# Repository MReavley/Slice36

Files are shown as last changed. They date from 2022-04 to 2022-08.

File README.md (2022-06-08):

# Slice36 Minimalist Split Keyboard

Picture of the Slice36

36 key ergo split keyboard, designed around the Seeeduino Xiao platform. Inspired by the Corne, Ferris, Ben Vallack's videos and countless hours of perusing reddit and kbd.news, but ultimately this has been done up from scratch largely as an exercise for myself. The layout was generated through experimentation with scale drawings on my ipad, although emphasis has been placed on aesthetics and compactness. 

## Features

-MX Spacing  
-Reversible PCB, designed around 0805 smd components to be hand-solderable or using an assembly service.  
-Built around the Seeeduino Xiao RP2040(hooray USB-C), using KMK.  
-Laser cut aluminium plate, secured by the soldered in switches for clean look without fasteners  

Picture of the Slice36 and PCB

## BOM
-Seeeduino Xiao RP2040 x2  
-1N4148WS Diodes (SOD-323) x36  
-PJ320D TRRS jacks x2  
-0805 10k resistors x6   
-(additional footprints R4-R7 for I2C communication for splits, may not be required)  
-Cherry MX style switches x36  
-Plate x2   
-TRRS cable  

## Things to note if you want to build one:

-IMPORTANT: The xiao on the right half (master) is to be soldered with the LED/chip facing up, and the left half (slave) upside down, so that the pinout still matches the flipped PCB.  

-You can find the schematic, layout and gerbers in the repo, as well as a dxf file for the plate. I am currently working on a case for this and will add the stls and solidworks files once they are ready. 

-I use 8mm rubber feet that are 1.5mm tall which are just about tall enough, but I think taller rubber feet would be better.

-TRRS jacks for the split are connected to the I2C pins on the Xiao board. Since KMK uses UART for split communications, I used PIO on the RP2040 to change those pins to UART, but I don't know what your options are on the SAMD21 version if you wish to use UART on those.  

-From my first prototype, I found that the SAMD21 version of the Xiao required external pullups on the I2C lines, so I added those to this board, and I have not tested if they are necessary yet. Currently I am using 10k resistors (to simplify my BOM), and it is working fine.  

-The Xiao BLE version should also be compatible with this board, but I have not made any provisions for batteries on this version. In theory only minimal modifications would be necessary to get this going though.  

Picture of the Slice36 and PCB
Picture of the Slice36 and PCB

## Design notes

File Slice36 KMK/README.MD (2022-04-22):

Added the files I use with my current board (including my keymap with some custom macros). 
Also added the mpy file needed to use pio with the board for convenience.

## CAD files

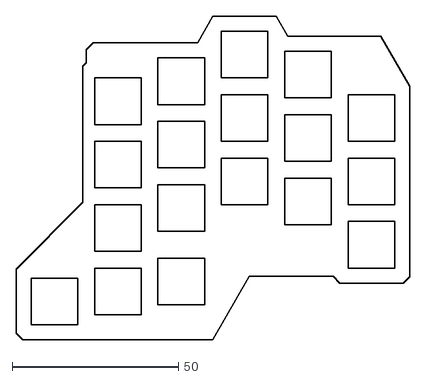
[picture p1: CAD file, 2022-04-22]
Plate/Slice36 Plate.dxf
118.3 x 97.2

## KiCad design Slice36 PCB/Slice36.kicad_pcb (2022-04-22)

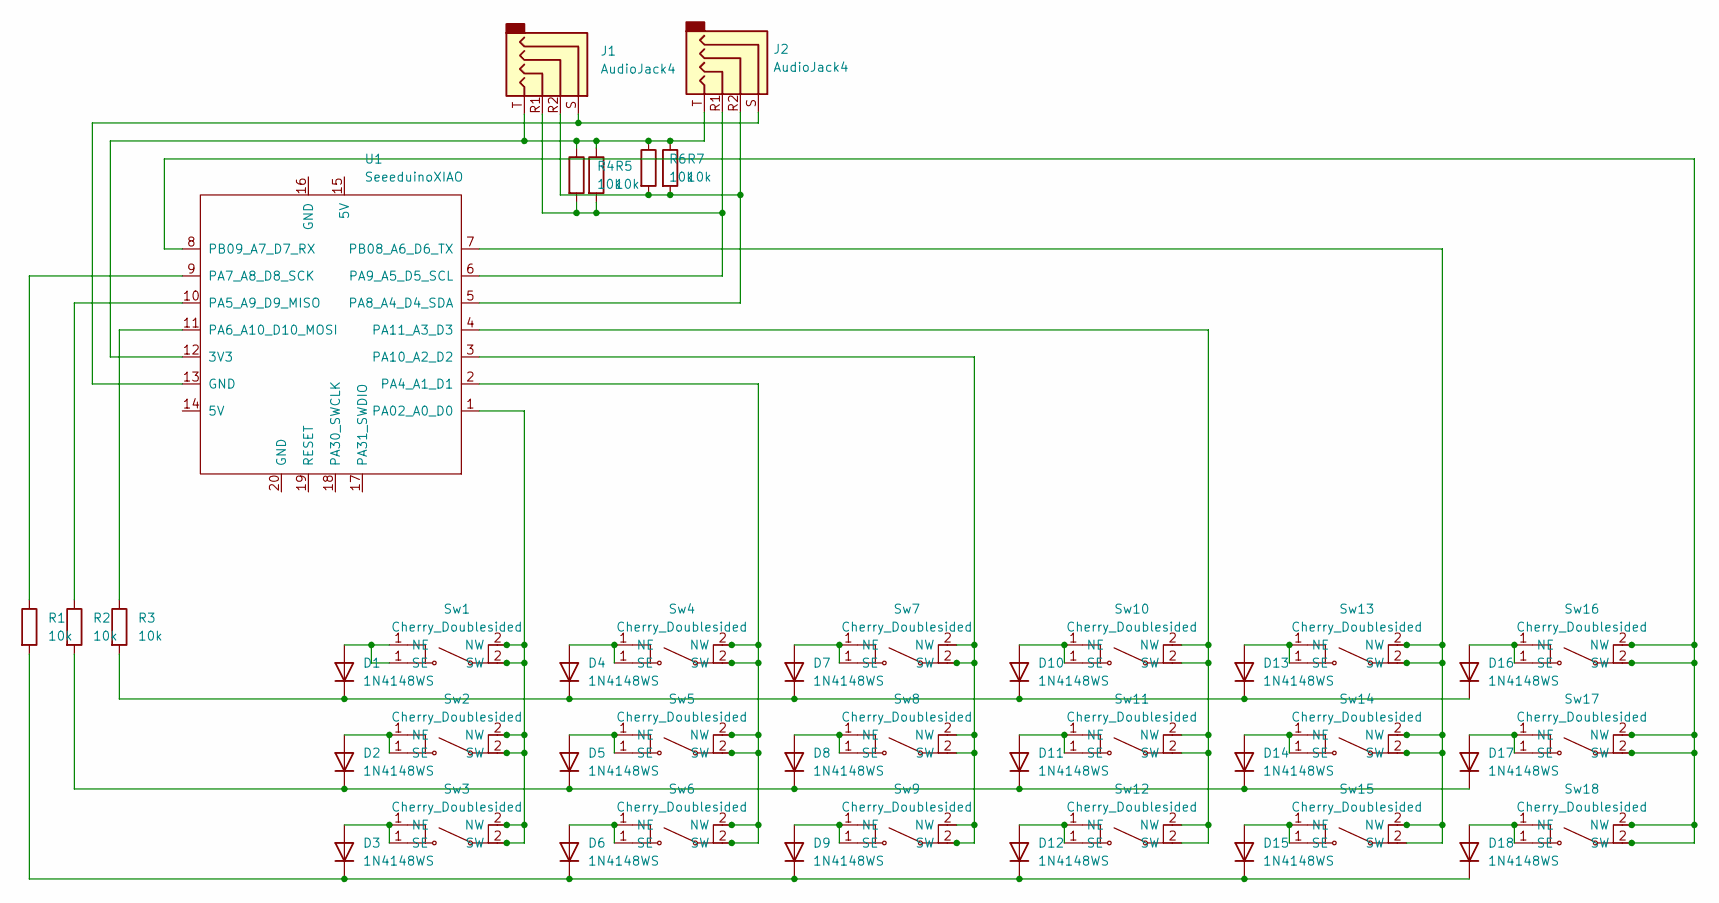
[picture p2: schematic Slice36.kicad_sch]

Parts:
D1, D2, D3, D4, D5, D6, D7, D8, D9, D10, D11, D12, D13, D14, D15, D16, D17, D18: 1N4148WS; D_SOD-323_HandSoldering
J1, J2: AudioJack4; Jack_3.5mm_PJ320D_Horizontal
R1, R2, R3, R4, R5, R6, R7: 10k; R_0805_2012Metric_Pad1.20x1.40mm_HandSolder
Sw1, Sw2, Sw3, Sw4, Sw5, Sw6, Sw7, Sw8, Sw9, Sw10, Sw11, Sw12, Sw13, Sw14, Sw15, Sw16, Sw17, Sw18: Cherry_Doublesided; SW_MX_reversible
U1: SeeeduinoXIAO; Seeeduino XIAO-MOUDLE14P-2.54-21X17.8MM

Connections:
unnamed: D1.1 (K), D4.1 (K), D7.1 (K), D10.1 (K), D13.1 (K), D16.1 (K), R3.2
unnamed: D1.2 (A), Sw1.1 (NE)
unnamed: D2.2 (A), Sw2.1 (NE)
unnamed: D3.2 (A), Sw3.1 (NE)
unnamed: D4.2 (A), Sw4.1 (NE)
unnamed: D5.2 (A), Sw5.1 (NE)
unnamed: D6.2 (A), Sw6.1 (NE)
unnamed: D7.2 (A), Sw7.1 (NE)
unnamed: D8.2 (A), Sw8.1 (NE)
unnamed: D9.2 (A), Sw9.1 (NE)
unnamed: D10.2 (A), Sw10.1 (NE)
unnamed: D2.1 (K), D5.1 (K), D8.1 (K), D11.1 (K), D14.1 (K), D17.1 (K), R2.2
unnamed: D11.2 (A), Sw11.1 (NE)
unnamed: D3.1 (K), D6.1 (K), D9.1 (K), D12.1 (K), D15.1 (K), D18.1 (K), R1.2
unnamed: D12.2 (A), Sw12.1 (NE)
unnamed: D13.2 (A), Sw13.1 (NE)
unnamed: D14.2 (A), Sw14.1 (NE)
unnamed: D16.2 (A), Sw16.1 (NE)
unnamed: D17.2 (A), Sw17.1 (NE)
unnamed: D18.2 (A), Sw18.1 (NE)
unnamed: J1.R1, J2.R1, R4.2, R5.2, U1.6 (PA9_A5_D5_SCL)
unnamed: J1.R2, J2.R2, R6.2, R7.2, U1.5 (PA8_A4_D4_SDA)
unnamed: J1.S, J2.S, U1.13 (GND)
unnamed: J1.T, J2.T, R4.1, R5.1, R6.1, R7.1, U1.12 (3V3)
unnamed: R1.1, U1.9 (PA7_A8_D8_SCK)
unnamed: R2.1, U1.10 (PA5_A9_D9_MISO)
unnamed: R3.1, U1.11 (PA6_A10_D10_MOSI)
unnamed: Sw1.2 (NW), Sw2.2 (NW), Sw3.2 (NW), U1.1 (PA02_A0_D0)
unnamed: Sw4.2 (SW), Sw5.2 (SW), Sw6.2 (NW), U1.2 (PA4_A1_D1)
unnamed: Sw7.2 (NW), Sw8.2 (NW), Sw9.2 (NW), U1.3 (PA10_A2_D2)
unnamed: Sw10.2 (NW), Sw11.2 (NW), Sw12.2 (NW), U1.4 (PA11_A3_D3)
unnamed: D15.2 (A), Sw15.1 (NE)
unnamed: Sw13.2 (SW), Sw14.2 (SW), Sw15.2 (SW), U1.7 (PB08_A6_D6_TX)
unnamed: Sw16.2 (SW), Sw17.2 (NW), Sw18.2 (NW), U1.8 (PB09_A7_D7_RX)

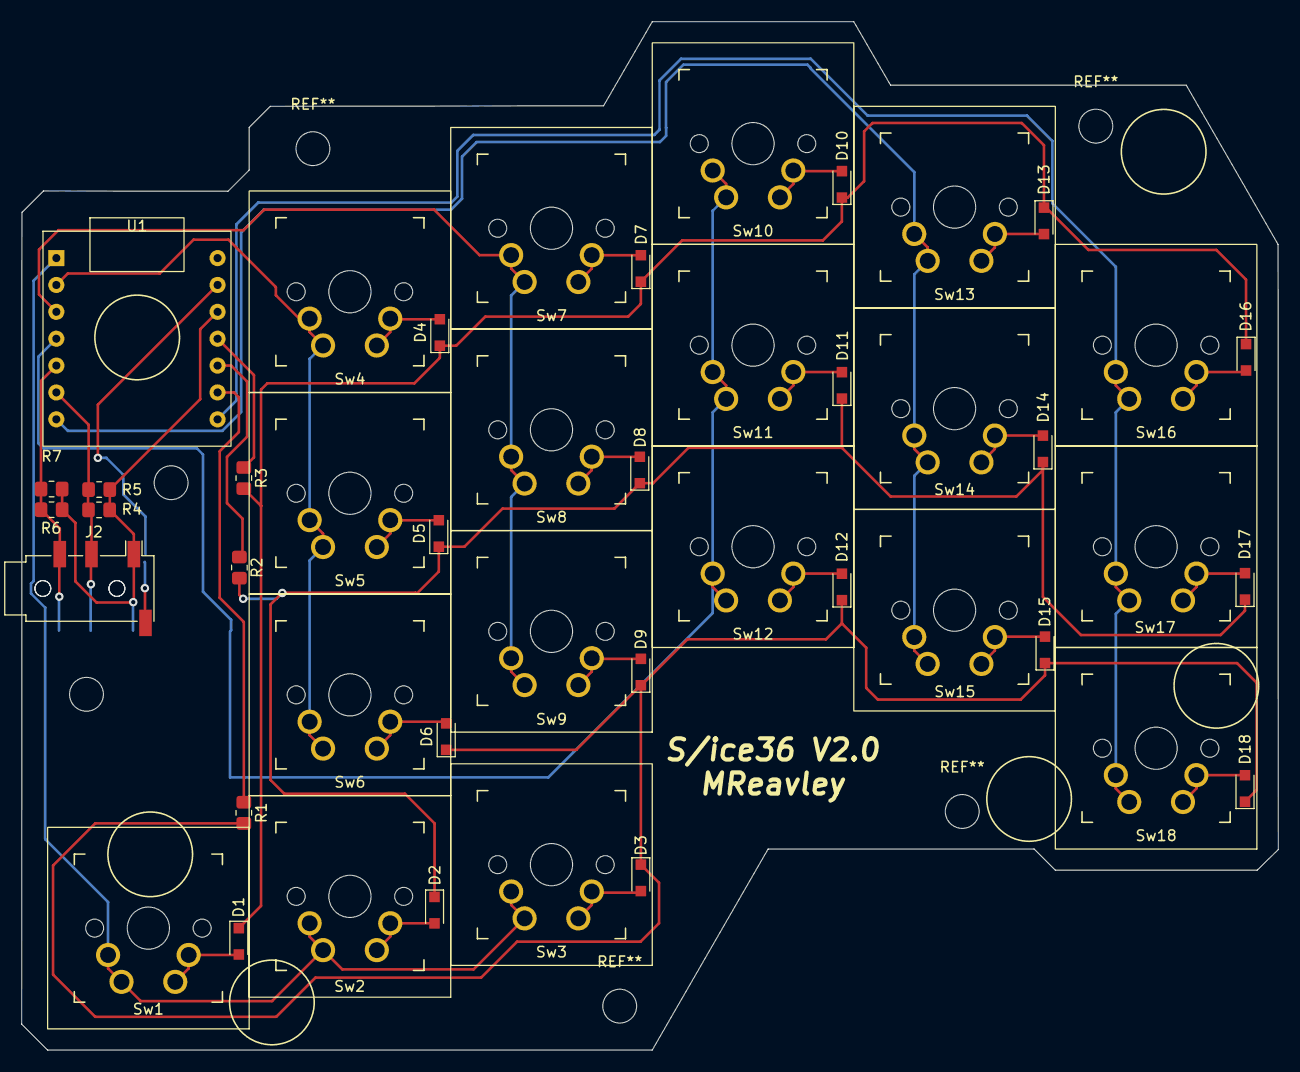
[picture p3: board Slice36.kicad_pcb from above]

Board: 2 copper layers, 118.8 x 97.2 mm, 46 parts (1 on the bottom side), 34 nets.

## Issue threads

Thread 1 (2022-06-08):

Bill of materials

nerdypepper, 2022-06-08:
Would you happen to have a bill of materials for this build? I am looking to build the Slice36 up from scratch and a BOM would help greatly in assembly and orders, cheers!

MReavley, 2022-06-08:
Hi, just added one to the Readme! You could probably edit the PCB to use SOD-123 diodes instead of the SOD-323 diodes I used, and also probably flip the orientation of D1-3, D13 and D16 to avoid trip-ups if you feel comfortable to do so. Otherwise, just note the orientation when you are soldering those in.

nerdypepper, 2022-06-09:
Awesome, thanks for your work!

Closed 2022-06-09.

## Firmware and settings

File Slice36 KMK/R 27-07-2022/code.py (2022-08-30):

import board

from kb import KMKKeyboard

import adafruit_pioasm
import neopixel

from digitalio import DigitalInOut, Direction ,Pull

#from kmk.kmk_keyboard import KMKKeyboard
from kmk.keys import KC
from kmk.matrix import DiodeOrientation
from kmk.modules.split import Split, SplitSide, SplitType
from kmk.modules.layers import Layers
from kmk.modules.modtap import ModTap
from kmk.modules.mouse_keys import MouseKeys
from kmk.extensions.media_keys import MediaKeys
from kmk.extensions.lock_status import LockStatus
from kmk.handlers.sequences import simple_key_sequence
from kmk.extensions.RGB import RGB

#pixel_pin = board.NEOPIXEL
#num_pixels = 1
rgb_ext = RGB(pixel_pin = board.NEOPIXEL, num_pixels=1, hue_default= 0, val_limit=10,
              val_default=10, hue_step=18)
#rgb_ext.rgb_config['hue_default']= 200
#rgb_ext.rgb_config['val_limit'] = 50

#pixels=neopixel.NeoPixel(pixel_pin, num_pixels, brightness = 0.05, auto_write=False)

#pixels[0]= (0,255,255)
#pixels.show()

red = DigitalInOut(board.LED_RED)
red.direction = Direction.OUTPUT
red.value = 1

green = DigitalInOut(board.LED_GREEN)
green.direction = Direction.OUTPUT
green.value = 1

blue = DigitalInOut(board.LED_BLUE)
blue.direction = Direction.OUTPUT
blue.value = 1


keyboard = KMKKeyboard()

modtap = ModTap()

mousekeys=MouseKeys()




split_side = SplitSide.RIGHT
#split_side = SplitSide.LEFT

split = Split(split_flip=True,split_type=SplitType.UART, split_side=split_side, use_pio=True,
split_target_left=False, target_left=False, data_pin= board.D5,
data_pin2=board.D4)

layers_ext = Layers()
locks = LockStatus()


keyboard.modules.append(split)
keyboard.modules.append(layers_ext)
keyboard.modules.append(modtap)
keyboard.modules.append(mousekeys)
keyboard.extensions.append(MediaKeys())
keyboard.extensions.append(locks)
keyboard.extensions.append(rgb_ext)

# Cleaner key names
_______ = KC.TRNS
XXXXXXX = KC.NO

QWERTY = simple_key_sequence((KC.TO(0),KC.RGB_M_P))
LOWER = KC.MO(1)
RAISE = KC.MO(2)
COMBO = KC.MO(3)
GAME =  simple_key_sequence((KC.TO(4),KC.RGB_M_BR))
GAME2 = KC.MO(5)

#Press and hold for modifiers
HLCtrl = KC.MT(KC.Z, KC.LCTL)
HLAlt = KC.MT(KC.X, KC.LALT)
HLGUI = KC.MT(KC.C, KC.LGUI)

HRCtrl = KC.MT(KC.SLSH, KC.LCTL)
HRAlt = KC.MT(KC.DOT, KC.LALT)
HRGUI = KC.MT(KC.COMM, KC.LGUI)


#Macros 
Scnshot = KC.LGUI(KC.LSFT(KC.S))
TManager = KC.LCTL(KC.LSFT(KC.ESC))
    
NTab = KC.LCTL(KC.TAB)
PTab = KC.LCTL(KC.LSFT(KC.TAB))

Undo = KC.LCTL(KC.Z)

RunPython = KC.LCTL(KC.LSFT(KC.B))

keyboard.keymap = [
    [  #QWERTY
        KC.Q,    KC.W,    KC.E,    KC.R,    KC.T,             KC.Y,    KC.U,    KC.I,    KC.O,   KC.P,    \
        KC.A,    KC.S,    KC.D,    KC.F,    KC.G,             KC.H,    KC.J,    KC.K,    KC.L, KC.QUOT,   \
        HLCtrl,  HLAlt,   KC.C,    KC.V,    KC.B,             KC.N,    KC.M,   HRGUI,   HRAlt,  HRCtrl,   \
                        KC.LSFT,   KC.SPC,  LOWER,            RAISE,   KC.BSPC,  KC.ENT,
    ],
    [  #LOWER
        KC.ESC,  PTab,    KC.UP,   NTab,    XXXXXXX,          KC.PLUS, KC.N7,  KC.N8,  KC.N9,  KC.EQL, \
        KC.TAB,  KC.LEFT, KC.DOWN, KC.RGHT, KC.LPRN,          KC.MINS, KC.N4,  KC.N5,  KC.N6,  KC.ASTR, \
          Undo,  KC.ENT,  KC.DEL,  KC.BSPC, KC.RPRN,          KC.N0,   KC.N1,  KC.N2,  KC.N3,  XXXXXXX, \
                          XXXXXXX, KC.LGUI, LOWER,            COMBO,   KC.DEL, KC.TAB,
    ],
    [  #RAISE
        KC.TILD,   KC.EXLM, KC.AT,   KC.HASH, KC.DLR,         KC.MB_MMB, KC.MB_LMB, KC.MS_UP, KC.MB_RMB, KC.AMPR, \
        KC.PGUP,   KC.VOLU, KC.PIPE, KC.LBRC, KC.LCBR,        KC.MW_UP,  KC.MS_LT,  KC.MS_DN, KC.MS_RT,  KC.CIRC, \
        KC.PGDOWN, KC.VOLD, PTab,    KC.RBRC, KC.RCBR,        KC.MW_DN,  KC.COLN,   KC.SCLN,  KC.UNDS,   KC.BSLS, \
                            XXXXXXX, XXXXXXX, COMBO,          RAISE,     XXXXXXX,   XXXXXXX,
    ],
    
    [  #COMBO
        KC.GRV , KC.F1,   KC.F2,   KC.F3,   KC.F4,            KC.HOME, XXXXXXX, XXXXXXX,XXXXXXX,TManager, \
        KC.INS,  KC.F5,   KC.F6,   KC.F7,   KC.F8,            KC.END, XXXXXXX, XXXXXXX, XXXXXXX,Scnshot,   \
        KC.NLCK, KC.F9,   KC.F10,  KC.F11,  KC.F12,           KC.MW_DN,XXXXXXX,XXXXXXX,XXXXXXX,RunPython,         \
                          GAME,    XXXXXXX, XXXXXXX,          XXXXXXX,XXXXXXX,XXXXXXX,
    ],
    
    [  #GAME
        KC.LALT , KC.Q , KC.W , KC.E , KC.R,     KC.MB_MMB, KC.MB_LMB, KC.MS_UP,KC.MB_RMB,XXXXXXX,
        KC.TAB  , KC.A, KC.S,  KC.D  , KC.F ,    KC.MW_UP, KC.MS_LT, KC.MS_DN, KC.MS_RT,XXXXXXX, 
        KC.LCTL, KC.Z, KC.X, KC.C, KC.V,       KC.MW_DN,XXXXXXX,XXXXXXX,XXXXXXX,XXXXXXX,
                       KC.LSFT, KC.SPC, GAME2,    XXXXXXX,   XXXXXXX,  QWERTY, 
    ],
    
    [   #GAME2
        KC.ESC,   KC.I, KC.T, KC.N1,  KC.N4,         XXXXXXX, XXXXXXX,  XXXXXXX, XXXXXXX,  XXXXXXX, \
        KC.CAPS,  KC.B, KC.G, KC.N2,  KC.N5,         XXXXXXX, XXXXXXX,  XXXXXXX, XXXXXXX,  XXXXXXX, \
        XXXXXXX,  KC.J, KC.M, KC.N3,  KC.N6,         XXXXXXX, XXXXXXX, XXXXXXX,XXXXXXX,  XXXXXXX, \
                      XXXXXXX, XXXXXXX,XXXXXXX,         XXXXXXX,  XXXXXXX,  XXXXXXX,

        
        
    ]   
]

class _LockStatus(LockStatus):
    def during_bootup(self, sandbox):
        self.caps_lock_led = blue
    def after_hid_send(self, sandbox):
        super().after_hid_send(sandbox)
        self.caps_lock_led.value = not(self.get_caps_lock())
    
keyboard.extensions.append(_LockStatus())




if __name__ == '__main__':
    keyboard.go()

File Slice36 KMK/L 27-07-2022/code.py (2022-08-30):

import board

from kb import KMKKeyboard

import adafruit_pioasm

#from kmk.kmk_keyboard import KMKKeyboard
from kmk.keys import KC
from kmk.matrix import DiodeOrientation
from kmk.modules.split import Split, SplitSide, SplitType
from kmk.modules.layers import Layers

keyboard = KMKKeyboard()

#split_side = SplitSide.RIGHT
split_side = SplitSide.LEFT

split = Split(split_flip=False,split_type=SplitType.UART, split_side=split_side, use_pio=True,
split_target_left=False, target_left=False, data_pin= board.D5,
data_pin2=board.D4)

layers_ext = Layers()

keyboard.modules.append(split)
keyboard.modules.append(layers_ext)
    
keyboard.col_pins = (board.D0, board.D1, board.D2, board.D3, board.D6, board.D7 )
keyboard.row_pins = (board.D10, board.D9, board.D8)
keyboard.diode_orientation = DiodeOrientation.COL2ROW

# Cleaner key names
_______ = KC.TRNS
XXXXXXX = KC.NO

LOWER = KC.MO(1)
RAISE = KC.MO(2)
ADJUST = KC.LT(3, KC.SPC)



keyboard.keymap = [
    [  #QWERTY
        KC.Q,    KC.W,    KC.E,    KC.R,    KC.T,                     KC.Y,    KC.U,    KC.I,    KC.O,   KC.P,  \
        KC.A,    KC.S,    KC.D,    KC.F,    KC.G,                     KC.H,    KC.J,    KC.K,    KC.L, KC.SCLN, \
        KC.Z,    KC.X,    KC.C,    KC.V,    KC.B,                     KC.N,    KC.M, KC.COMM,  KC.DOT, KC.SLSH, \
                            KC.LGUI,   LOWER,  ADJUST,     KC.ENT,   RAISE,  KC.RALT,
    ],
    [  #LOWER
        KC.ESC,   KC.N1,   KC.N2,   KC.N3,   KC.N4,   KC.N5,                         KC.N6,   KC.N7,  KC.N8,   KC.N9,   KC.N0, KC.BSPC,\
        KC.LCTL, XXXXXXX, XXXXXXX, XXXXXXX, XXXXXXX, XXXXXXX,                        KC.LEFT, KC.DOWN, KC.UP,   KC.RIGHT, XXXXXXX, XXXXXXX,\
        KC.LSFT, XXXXXXX, XXXXXXX, XXXXXXX, XXXXXXX, XXXXXXX,                        XXXXXXX, XXXXXXX, XXXXXXX, XXXXXXX, XXXXXXX, XXXXXXX,\
                                            KC.LGUI,   LOWER,  ADJUST,     KC.ENT,   RAISE,  KC.RALT,
    ],
    [  #RAISE
        KC.ESC, KC.EXLM,   KC.AT, KC.HASH,  KC.DLR, KC.PERC,                         KC.CIRC, KC.AMPR, KC.ASTR, KC.LPRN, KC.RPRN, KC.BSPC,\
        KC.LCTL, XXXXXXX, XXXXXXX, XXXXXXX, XXXXXXX, XXXXXXX,                        KC.MINS,  KC.EQL, KC.LCBR, KC.RCBR, KC.PIPE,  KC.GRV,\
        KC.LSFT, XXXXXXX, XXXXXXX, XXXXXXX, XXXXXXX, XXXXXXX,                        KC.UNDS, KC.PLUS, KC.LBRC, KC.RBRC, KC.BSLS, KC.TILD,\
                                            KC.LGUI,   LOWER,  ADJUST,     KC.ENT,   RAISE,  KC.RALT,
    ]
]



if __name__ == '__main__':
    keyboard.go()
